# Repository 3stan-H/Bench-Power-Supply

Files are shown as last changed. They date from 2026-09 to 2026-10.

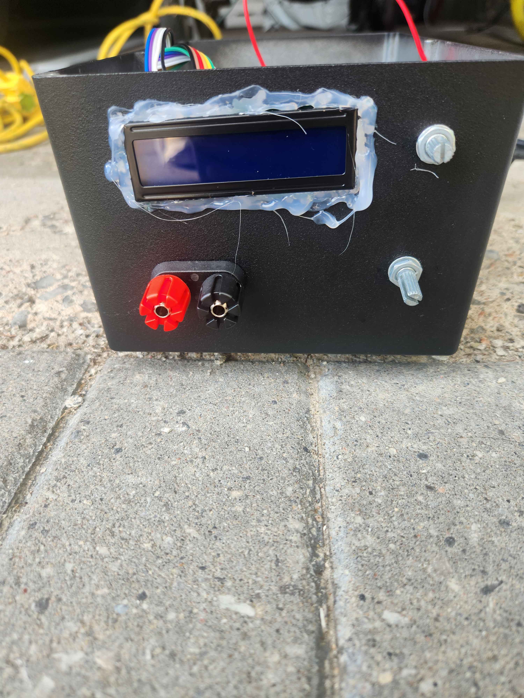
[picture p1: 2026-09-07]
Front.jpg

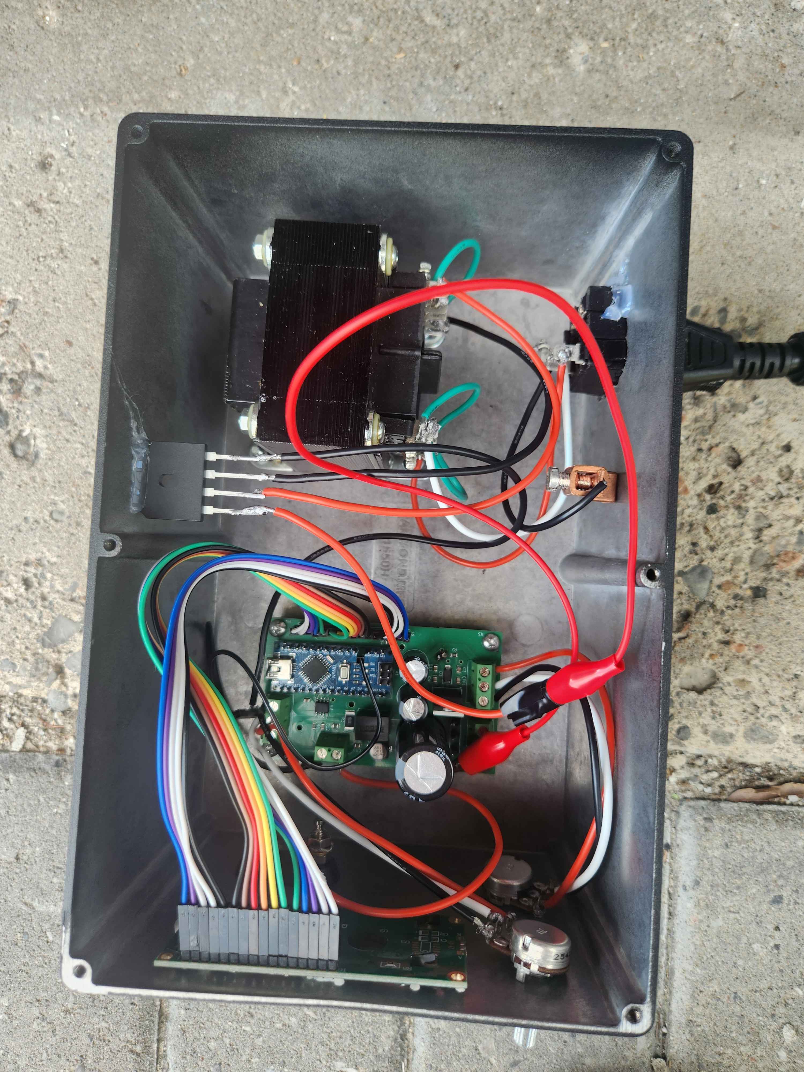
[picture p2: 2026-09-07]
Top.jpg

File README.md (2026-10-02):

# Bench Power Supply

## Overview
A mains-powered, adjustable bench power supply designed in KiCad, converting 120V AC wall input into a regulated 1–20V DC output. The design integrates real-time voltage/current monitoring and follows mains electrical safety practices for isolating AC and low-voltage DC domains. The complete unit was built for approximately $90 in components — roughly 50% less than similarly-specced commercial digital bench supplies ($130–$200 retail).

## Objectives
- Design a safe, mains-powered adjustable DC power supply from raw 120V AC input
- Provide fine-grained, real-time output voltage adjustment
- Display live output voltage and current readings during use
- Follow mains electrical safety practices to protect against shock hazards
- Deliver the unit at a significant cost saving over comparable commercial supplies

## Key Components
- **AC Input Stage** — IEC inlet, fuse, step-down transformer, bridge rectifier
- **Buck Converter** — XL4016, regulating output to 2–5V DC
- **Feedback Network** — potentiometer + resistor divider on the buck converter's feedback pin, enabling 0.01V adjustment resolution
- **Current Sensing** — INA219 current-sensing IC
- **Display/Control** — Arduino Nano driving an LCD screen, showing live voltage/current accurate to 0.01V/0.01A

## Signal Chain
IEC Inlet → Fuse → Transformer → Bridge Rectifier → XL4016 Buck Converter → Regulated 2–5V DC Output

## Files
- `Bench_Power_Supply.kicad_pro` — project file
- `Bench_Power_Supply.kicad_sch` — full schematic (AC input stage, buck converter, feedback network, current-sensing and display circuitry)
- `Bench_Power_Supply.kicad_pcb` — PCB layout (AC-safety and low-voltage DC routing kept separate)
- `gerbers/` — fabrication output (Gerber, drill files)
- `firmware/` — Arduino Nano source code for the INA219 readout and LCD display
- `Bench_Power_Supply_3D.png` — 3D rendered board preview

## Design Notes
- **Voltage Regulation**: The XL4016 buck converter's feedback pin is tuned via a potentiometer/resistor-divider network, giving real-time output adjustment in 0.01V steps across the 1–20V range.
- **Monitoring**: An INA219 current-sensing IC feeds live voltage and current data to an Arduino Nano, which drives an LCD display accurate to 0.01V/0.01A for real-time monitoring during use.
- **Mains Safety**: The chassis (earth) ground is isolated from the circuit's PCB ground rail at the IEC inlet, protecting against electrical shock hazards. AC-safety and low-voltage DC routing are kept physically separated on the PCB layout.
- **Cost**: Total build cost was approximately $90 in components, roughly 50% less than similarly-specced commercial digital bench power supplies (typically $130–$200 retail).

## Status
Designed, laid out, and built as a complete working unit — power regulation, voltage adjustment, and live voltage/current monitoring were all implemented and verified in the final build.

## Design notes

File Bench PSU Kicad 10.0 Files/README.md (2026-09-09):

This folder contains the project files for the Bench PSU through KiCad 10.0 as well as the BOM which represents the materials and components needed for this project with the MPN refering to the digikey part number. 

The BOM Also is missing a couple of things which include:

- Jumper Wires (MPN: 1954)
- 2x Potentiometers (MPN: PDB181-E420K-103B)

Keep in mind the schematic is missing some symbols which are present in "V2 Bench PSU KiCad 10.0 Files"

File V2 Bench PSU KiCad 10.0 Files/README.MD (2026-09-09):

This folder contains the same project however the errors that came up when assemblying the first version was fixed. This includes the missing ground on J4, as well as fixing the Pins of D1. Also includes the full BOM with the new schematic representing all the symbols. The BOM represents the materials and components needed for this project with the MPN refering to the digikey part number. 

The BOM Also is missing a couple of things which include:

- Jumper Wires (MPN: 1954)
- 2x Potentiometers (MPN: PDB181-E420K-103B)

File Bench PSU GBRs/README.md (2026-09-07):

This folder contains files for the Bench PSU Gerbers, Drill, and BOM files

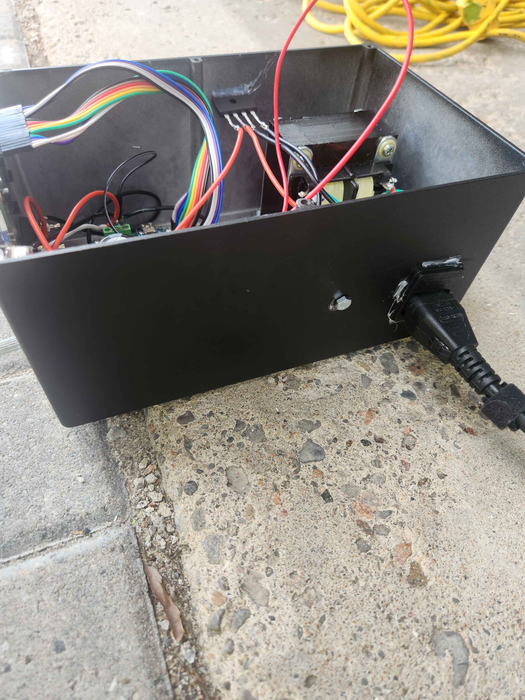
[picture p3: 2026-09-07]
Side.jpg

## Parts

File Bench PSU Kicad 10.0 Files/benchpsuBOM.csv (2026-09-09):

Reference | Qty | Value | Footprint | LCSC | MPN
A1 | 1 | Arduino_Nano_v3.x | Module:Arduino_Nano |  | 102010019
C1 | 1 | 4700u/50V | Capacitor_THT:CP_Radial_D16.0mm_P7.50mm | C5115284
C3,C4,C11 | 3 | 1u | Capacitor_SMD:C_0805_2012Metric | C28323
C5,C10,C12 | 3 | 100n | Capacitor_SMD:C_0805_2012Metric | C126469
C6 | 1 | 470u/50V | Capacitor_THT:CP_Radial_D10.0mm_P5.00mm | C346975
C7 | 1 | 1000u/25V | Capacitor_THT:CP_Radial_D10.0mm_P5.00mm | C503217
C9 | 1 | 100u/16V | Capacitor_SMD:CP_Elec_6.3x5.4 | C346929
CFF1 | 1 | 33n | Capacitor_SMD:C_0805_2012Metric | C1739
D1 | 1 | GBU1010 | Diode_THT:Diode_Bridge_19.0x3.5x10.0mm_P5.0mm |  | GBU1010
D3 | 1 | SS34 | Diode_SMD:D_SMA | C8678
DS1 | 1 | WC1602A |  |  | 181
F1 | 1 | Fuse |  |  | 5HT 2-R
J1 | 1 | IEC_60320_C14_Receptacle |  |  | 723W-X2/03
J2,J5 | 2 | Screw_Terminal_01x02 | TerminalBlock_Phoenix:TerminalBlock_Phoenix_PT-1,5-2-5.0-H_1x02_P5.00mm_Horizontal |  | 282837-2
J3,J4 | 2 | Screw_Terminal_01x03 | TerminalBlock_Phoenix:TerminalBlock_Phoenix_MKDS-1,5-3_1x03_P5.00mm_Horizontal |  | 282837-3
J6 | 1 | Connects to LCD | Connector_PinHeader_2.54mm:PinHeader_1x16_P2.54mm_Vertical | C7430372
L3 | 1 | 100u | Inductor_SMD:L_0805_2012Metric | C88184
R1,R6 | 2 | 10k | Resistor_SMD:R_0805_2012Metric | C17414
R2 | 1 | 3.3k | Resistor_SMD:R_0805_2012Metric | C26010
R3 | 1 | 0.1 | Resistor_SMD:R_2512_6332Metric | C844904
R4 | 1 | 100 | Resistor_SMD:R_0805_2012Metric | C702827
R5 | 1 | 47k | Resistor_SMD:R_0805_2012Metric | C29252
T1 | 1 | Transformer_1P_1S |  |  | VPS24-3300
U1 | 1 | XL4016 | Package_TO_SOT_SMD:XL4016 | C55881
U2 | 1 | INA219AxD | Package_SO:SOIC-8_3.9x4.9mm_P1.27mm | C138706
U3 | 1 | R-78C5.0-1.0 | Converter_DCDC:R-78C&slash_E-1.0_SIP3_11.6X8.5X10.4_RCP |  | R-78C5.0-1.0

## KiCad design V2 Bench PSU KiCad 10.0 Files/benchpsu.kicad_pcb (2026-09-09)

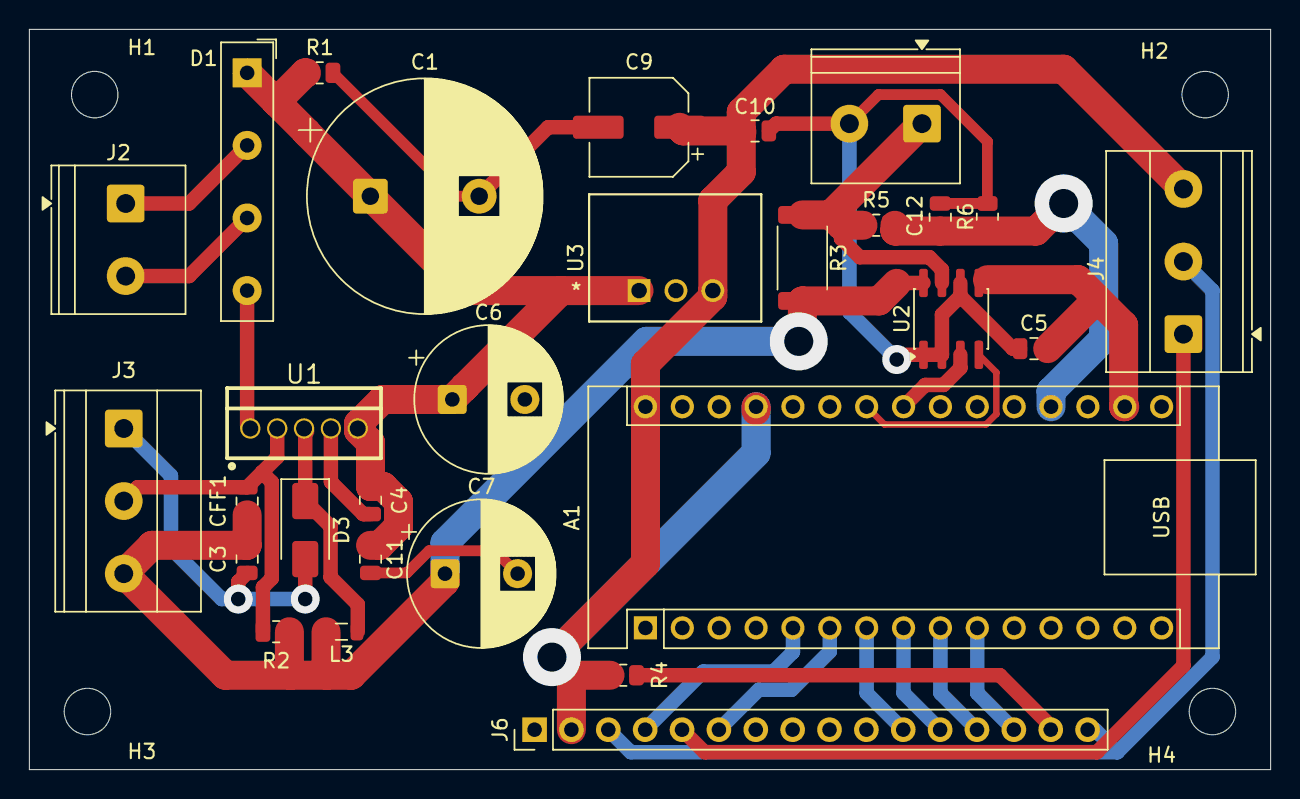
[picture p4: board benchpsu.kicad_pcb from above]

Board: 2 copper layers, 85.5 x 51.0 mm, 33 parts (0 on the bottom side), 22 nets.

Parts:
A1: Arduino_Nano_v3.x; Arduino_Nano
C1: 4700u/50V; CP_Radial_D16.0mm_P7.50mm
C3, C4, C11: 1u; C_0805_2012Metric
C5, C10, C12: 100n; C_0805_2012Metric
C6: 470u/50V; CP_Radial_D10.0mm_P5.00mm
C7: 1000u/25V; CP_Radial_D10.0mm_P5.00mm
C9: 100u/16V; CP_Elec_6.3x5.4
CFF1: 33n; C_0805_2012Metric
D1: GBU1010; Diode_Bridge_19.0x3.5x10.0mm_P5.0mm
D3: SS34; D_SMA
H1, H2, H3, H4: MountingHole; MountingHole_3.2mm_M3
J2, J5: Screw_Terminal_01x02; TerminalBlock_Phoenix_PT-1,5-2-5.0-H_1x02_P5.00mm_Horizontal
J3, J4: Screw_Terminal_01x03; TerminalBlock_Phoenix_MKDS-1,5-3_1x03_P5.00mm_Horizontal
J6: Connects to LCD; PinHeader_1x16_P2.54mm_Vertical
L3: 100u; L_0805_2012Metric
R1, R6: 10k; R_0805_2012Metric
R2: 3.3k; R_0805_2012Metric
R3: 0.1; R_2512_6332Metric
R4: 100; R_0805_2012Metric
R5: 47k; R_0805_2012Metric
U1: XL4016
U2: INA219AxD; SOIC-8_3.9x4.9mm_P1.27mm
U3: R-78C5.0-1.0; R-78C&slash_E-1.0_SIP3_11.6X8.5X10.4_RCP

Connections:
/3.3V: A1.17 (3V3), C5.1, U2.5 (VS)
/5V: A1.27 (+5V), A1.30 (VIN), C9.1, C10.1, J4.3, J6.2, R4.2, U3.3 (VO)
/+VOUT: C3.1, C7.1, CFF1.2, J3.3, L3.2, R2.1, R3.1, U2.8 (IN+)
/+VOUT_SENSE: J5.1, R3.2, R5.2, U2.7 (IN-)
/+VRAW: C1.1, C4.1, C6.1, C11.1, D1.1 (+), R1.1, U1.5 (VIN), U3.1 (VI)
/D2: A1.5 (D2), J6.4
/D3: A1.6 (D3), J6.6
/D4: A1.7 (D4), J6.11
/D5: A1.8 (D5), J6.12
/D6: A1.9 (D6), J6.13
/D7: A1.10 (D7), J6.14
/DS1PIN15: J6.15, R4.1
/J4PIN1: J4.1, J6.5
/SCL: A1.24 (A5), U2.4 (SCL)
/SDA: A1.23 (A4), U2.3 (SDA)
/ScrewTerminal1: D1.2, J2.1
/ScrewTerminal2: D1.3 (-), J2.2
/VOUT_SENSE: A1.19 (A0), C12.1, R5.1, R6.1
GND: A1.4 (GND), A1.29 (GND), C1.2, C3.2, C5.2, C6.2, C7.2, C9.2, C10.2, C11.2, C12.2, D1.4, D3.2 (A), J3.1, J4.2, J5.2, J6.1, J6.3, J6.16, R1.2, R6.2, U1.1 (GND), U2.1 (A1), U2.2 (A0), U2.6 (GND), U3.2 (GND)
unnamed: D3.1 (K), L3.1, U1.3 (OUT)
unnamed: CFF1.1, J3.2, R2.2, U1.2 (FB)
unnamed: C4.2, U1.4 (VC)
